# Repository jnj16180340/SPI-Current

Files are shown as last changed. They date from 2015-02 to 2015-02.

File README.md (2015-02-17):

# SPI-Current
Schematic and boards for power supply  

**Versions: **
Beefy and Wimpy: Wimpy has heatsinks+coils removed; traces are smaller; board is shrunk a lot

**TODO:**  
* Wall voltage fuse, stepdown, rectify, filter
* Make a branch with 2 independent half bridges in it
* Isolate the 12V stuff from the 5v stuff
* Figure out filtering caps for hall sensors
* Add fuse to output
* Lay out boards  

**NOTES:** 
* Traces won't take much current-- Only about 5 amps or so. Ideally we can OMIT the traces entirely and wire up with wire. Or, beel up the traces with solder by OMITTING the mask
* Use 10 gauge wire
* Replace shunt resistors x2 with thick wire jumper, unless you omit the hall sensors
* Replace a hall sensor with wire jumper unless you want two redundant ones
* Values for L#, may depend on the load
* Gain of output buffer: If ACS758 is 60mV/A, then max (50A) is 3. Want gain = 5/3
* 12V gets an XT60 connector, rated to 60A
* So does output to peltiers
* DIS jumper disables the drivers...
* If you power up the HIP4081 backwards it DIES.

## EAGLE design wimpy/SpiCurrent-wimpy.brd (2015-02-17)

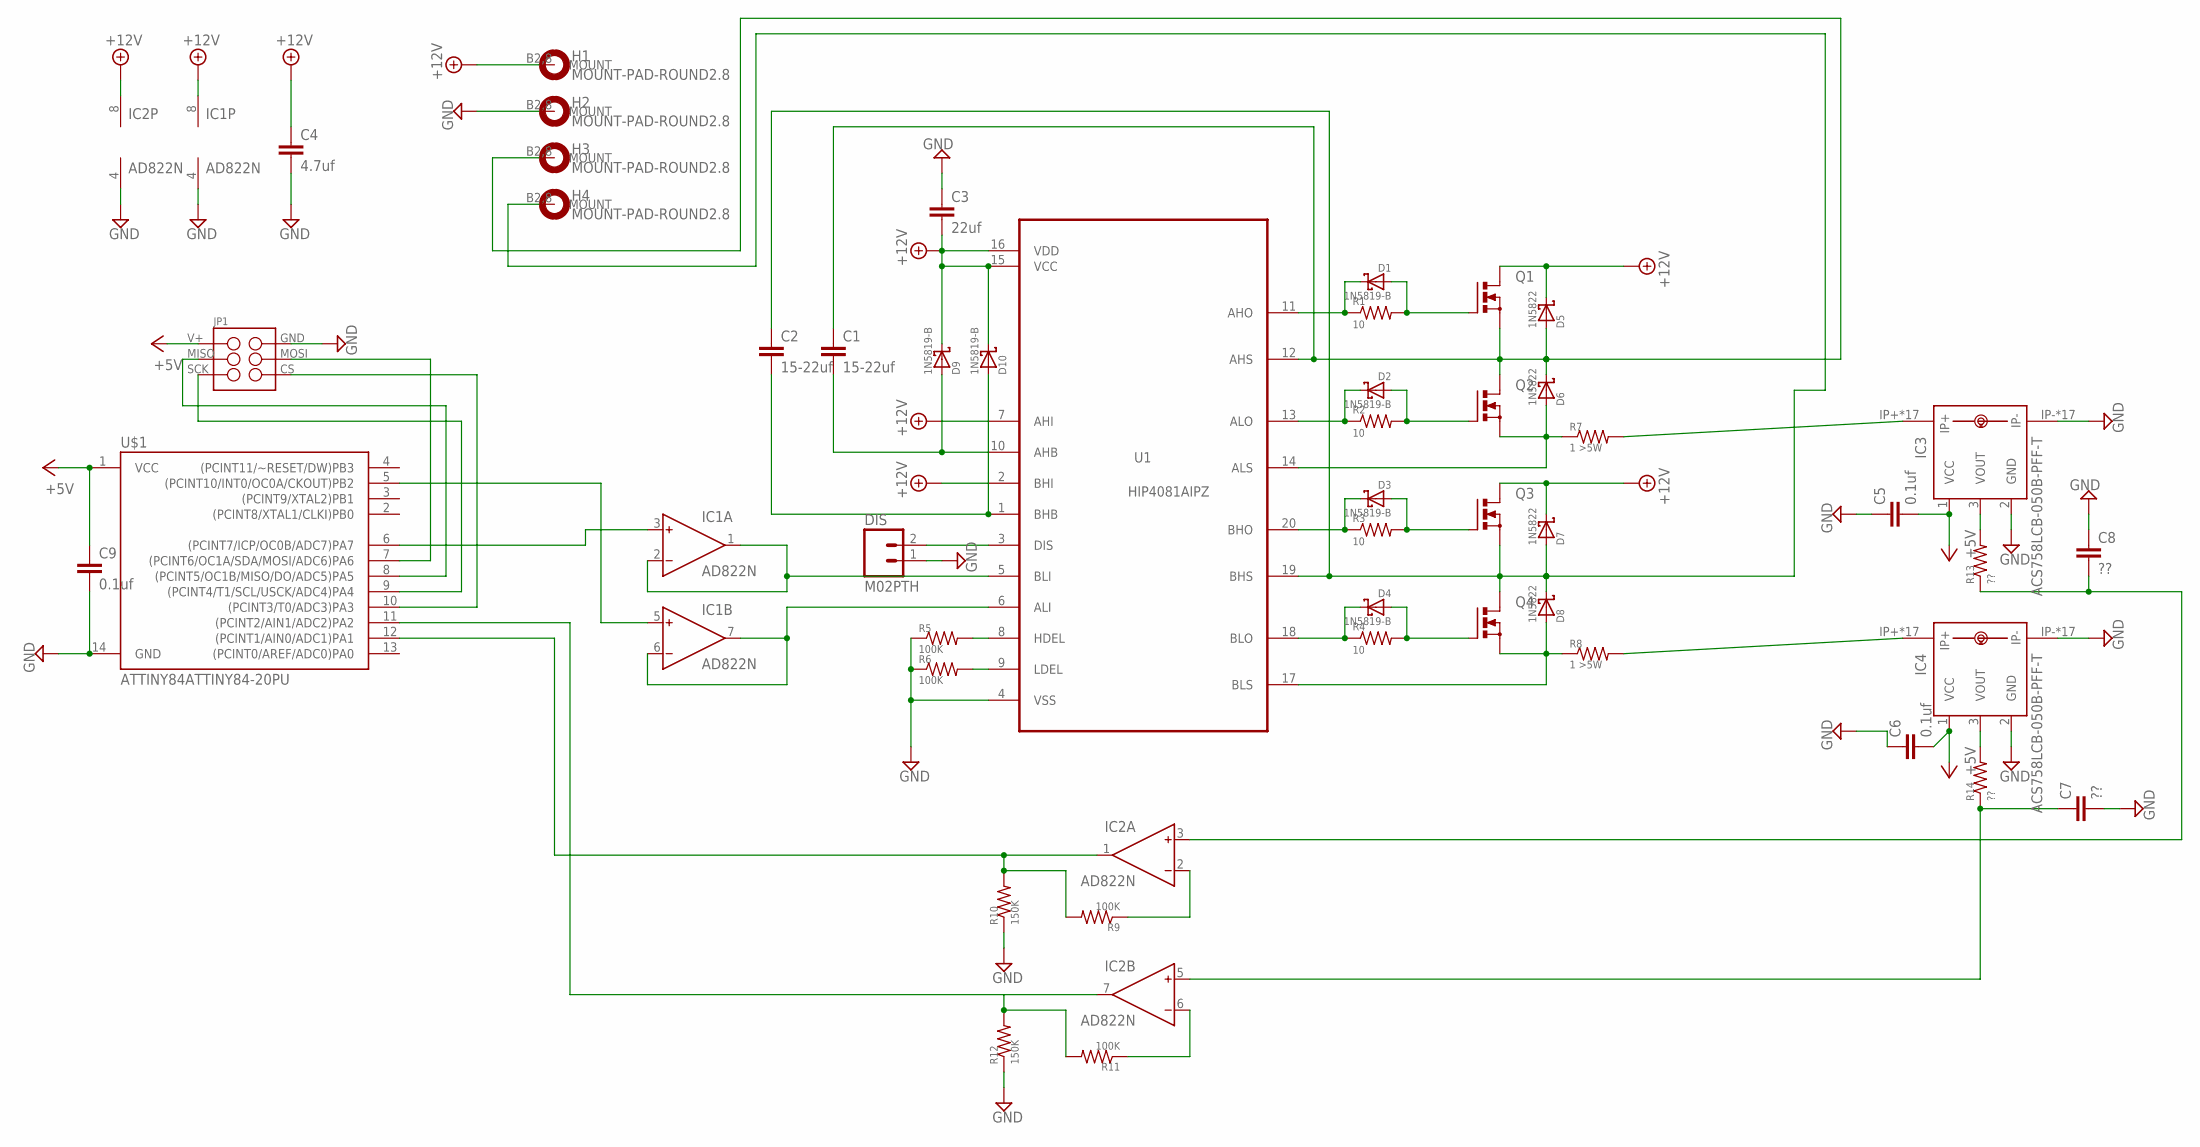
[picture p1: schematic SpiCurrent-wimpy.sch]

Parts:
C1, C2: 15-22uf; C050-055X075
C3: 22uf; C050-055X075
C4: 4.7uf; C050-055X075
C5, C6, C9: 0.1uf; C050-055X075
C7, C8: ??; C050-055X075
D1, D2, D3, D4, D9, D10: 1N5819-B; DO41-7.6
D5, D6, D7, D8: 1N5822; DO41-7.6
DIS: M02PTH; 1X02
H1, H2, H3, H4: MOUNT-PAD-ROUND2.8; 2,8-PAD
IC1, IC2: AD822N; DIL08
IC3, IC4: ACS758LCB-050B-PFF-T; CB-PFF
JP1: M03X2SHROUD; 2X3-SPI-SHROUDED
Q1, Q2, Q3, Q4: PMOSFET_NTO220BV; TO220BV
R1, R2, R3, R4: 10; 0207/10
R5, R6, R9, R11: 100K; 0207/10
R7, R8: 1 >5W; VTA54
R10, R12: 150K; 0207/10
R13, R14: ??; 0207/10
U1: HIP4081AIPZ; DIP254P762X533-20
U$1: ATTINY84ATTINY84-20PU; DIL14

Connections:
+5V: C5.2, C6.2, C9.1, IC3.1 (VCC), IC4.1 (VCC), JP1.1, U$1.1 (VCC)
+12V: C3.2, C4.1, D5.C, D7.C, D9.C, D10.C, H1.B2,8, IC1.8 (V+), IC2.8 (V+), Q1.D, Q3.D, U1.2 (BHI), U1.7 (AHI), U1.15 (VCC), U1.16 (VDD)
,JHBKLJN: C1.1, D5.A, D6.C, H3.B2,8, Q1.S, Q2.D, U1.12 (AHS)
GND: C3.1, C4.2, C5.1, C6.1, C7.2, C8.1, C9.2, DIS.1, H2.B2,8, IC1.4 (V-), IC2.4 (V-), IC3.2 (GND), IC3.IP-, IC3.IP-@2 (IP-), IC3.IP-@3 (IP-), IC3.IP-@4 (IP-), IC3.IP-@5 (IP-), IC3.IP-@6 (IP-), IC3.IP-@7 (IP-), IC3.IP-@8 (IP-), IC3.IP-@9 (IP-), IC3.IP-@10 (IP-), IC3.IP-@11 (IP-), IC3.IP-@12 (IP-), IC3.IP-@13 (IP-), IC3.IP-@14 (IP-), IC3.IP-@15 (IP-), IC3.IP-@16 (IP-), IC3.IP-@17 (IP-), IC4.2 (GND), IC4.IP-, IC4.IP-@2 (IP-), IC4.IP-@3 (IP-), IC4.IP-@4 (IP-), IC4.IP-@5 (IP-), IC4.IP-@6 (IP-), IC4.IP-@7 (IP-), IC4.IP-@8 (IP-), IC4.IP-@9 (IP-), IC4.IP-@10 (IP-), IC4.IP-@11 (IP-), IC4.IP-@12 (IP-), IC4.IP-@13 (IP-), IC4.IP-@14 (IP-), IC4.IP-@15 (IP-), IC4.IP-@16 (IP-), IC4.IP-@17 (IP-), JP1.2, R5.1, R6.1, R10.1, R12.1, U1.4 (VSS), U$1.14 (GND)
unnamed: IC1.1 (OUT), IC1.2 (IN-), U1.5 (BLI)
unnamed: IC1.6 (IN-), IC1.7 (OUT), U1.6 (ALI)
unnamed: D3.C, R3.1, U1.20 (BHO)
unnamed: D3.A, Q3.G, R3.2
unnamed: D4.C, R4.1, U1.18 (BLO)
unnamed: D4.A, Q4.G, R4.2
unnamed: D2.C, R2.1, U1.13 (ALO)
unnamed: D2.A, Q2.G, R2.2
unnamed: D1.C, R1.1, U1.11 (AHO)
unnamed: D1.A, Q1.G, R1.2
unnamed: R5.2, U1.8 (HDEL)
unnamed: R6.2, U1.9 (LDEL)
unnamed: C2.1, D7.A, D8.C, H4.B2,8, Q3.S, Q4.D, U1.19 (BHS)
unnamed: D6.A, Q2.S, R7.1, U1.14 (ALS)
unnamed: D8.A, Q4.S, R8.1, U1.17 (BLS)
unnamed: C1.2, D9.A, U1.10 (AHB)
unnamed: C2.2, D10.A, U1.1 (BHB)
unnamed: DIS.2, U1.3 (DIS)
unnamed: JP1.4, U$1.7 ((PCINT6/OC1A/SDA/MOSI/ADC6)PA6)
unnamed: JP1.3, U$1.8 ((PCINT5/OC1B/MISO/DO/ADC5)PA5)
unnamed: JP1.5, U$1.9 ((PCINT4/T1/SCL/USCK/ADC4)PA4)
unnamed: JP1.6, U$1.10 ((PCINT3/T0/ADC3)PA3)
unnamed: IC1.5 (IN+), U$1.5 ((PCINT10/INT0/OC0A/CKOUT)PB2)
unnamed: IC1.3 (IN+), U$1.6 ((PCINT7/ICP/OC0B/ADC7)PA7)
unnamed: IC2.2 (IN-), R9.1
unnamed: IC4.IP+, IC4.IP+@2 (IP+), IC4.IP+@3 (IP+), IC4.IP+@4 (IP+), IC4.IP+@5 (IP+), IC4.IP+@6 (IP+), IC4.IP+@7 (IP+), IC4.IP+@8 (IP+), IC4.IP+@9 (IP+), IC4.IP+@10 (IP+), IC4.IP+@11 (IP+), IC4.IP+@12 (IP+), IC4.IP+@13 (IP+), IC4.IP+@14 (IP+), IC4.IP+@15 (IP+), IC4.IP+@16 (IP+), IC4.IP+@17 (IP+), R8.2
unnamed: IC2.1 (OUT), R9.2, R10.2, U$1.12 ((PCINT1/AIN0/ADC1)PA1)
unnamed: IC2.7 (OUT), R11.2, R12.2, U$1.11 ((PCINT2/AIN1/ADC2)PA2)
unnamed: IC2.6 (IN-), R11.1
unnamed: IC3.IP+, IC3.IP+@2 (IP+), IC3.IP+@3 (IP+), IC3.IP+@4 (IP+), IC3.IP+@5 (IP+), IC3.IP+@6 (IP+), IC3.IP+@7 (IP+), IC3.IP+@8 (IP+), IC3.IP+@9 (IP+), IC3.IP+@10 (IP+), IC3.IP+@11 (IP+), IC3.IP+@12 (IP+), IC3.IP+@13 (IP+), IC3.IP+@14 (IP+), IC3.IP+@15 (IP+), IC3.IP+@16 (IP+), IC3.IP+@17 (IP+), R7.2
unnamed: C8.2, IC2.3 (IN+), R13.1
unnamed: C7.1, IC2.5 (IN+), R14.1
unnamed: IC3.3 (VOUT), R13.2
unnamed: IC4.3 (VOUT), R14.2

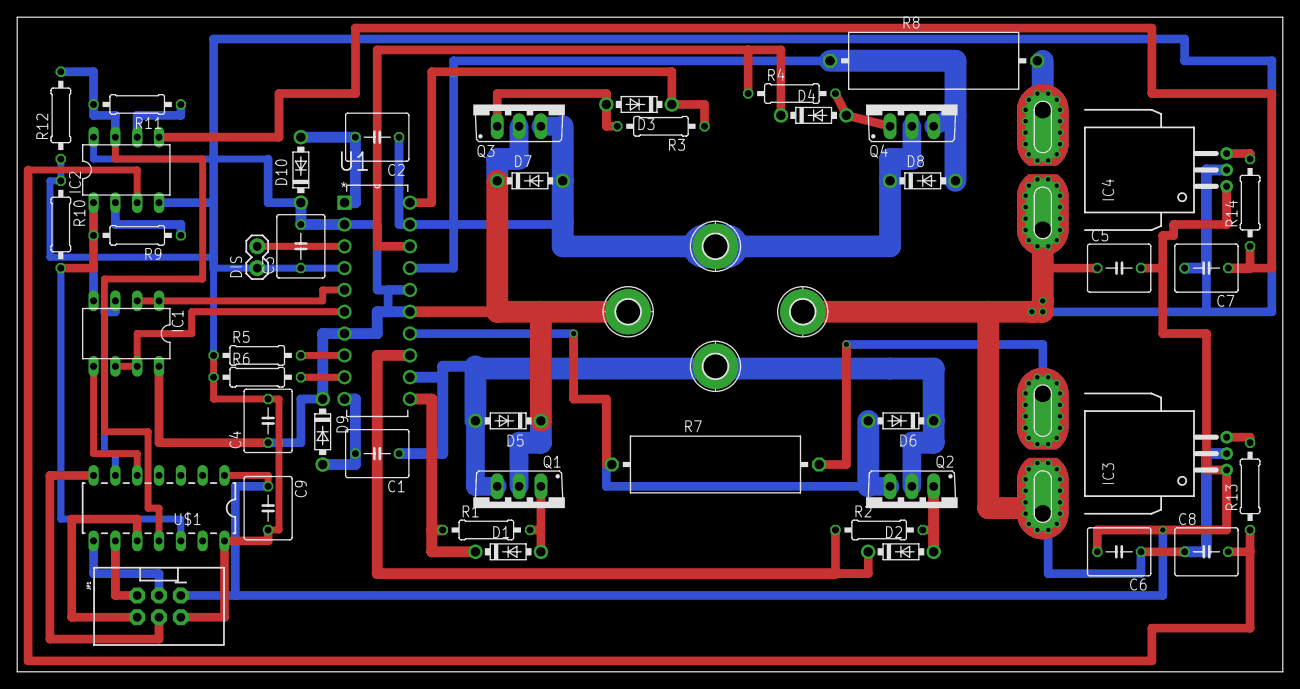
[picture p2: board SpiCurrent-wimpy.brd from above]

Board: 2 copper layers, 147.3 x 76.2 mm, 49 parts (0 on the bottom side), 38 nets.

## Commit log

2015-02-13 Added MCU and hall effect sensor
    [SpiCurrent-New.sch]
2015-02-14 barely begun layout
    [SpiCurrent-New.brd, SpiCurrent-Old-WithShunt.sch]
2015-02-15 begun layout
    [SpiCurrent-New.sch]
2015-02-15 Grossly laid out; still need to check (C5 is weird), check traces, adjust trace widths etc
    [SpiCurrent-New.brd]
2015-02-16 Layout complete. NB fancy mask stuff is NOT complete, use this one for low(ish) current testing
    [SpiCurrent-New.brd]
2015-02-17 Made beefy abnd wimpy versions
    [SpiCurrent-beefy.brd, SpiCurrent-beefy.sch, SpiCurrent-wimpy.brd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]
2015-02-17 removed old crap
    [SpiCurrent-New.brd, SpiCurrent-New.sch, SpiCurrent-Old-WithShunt.sch]

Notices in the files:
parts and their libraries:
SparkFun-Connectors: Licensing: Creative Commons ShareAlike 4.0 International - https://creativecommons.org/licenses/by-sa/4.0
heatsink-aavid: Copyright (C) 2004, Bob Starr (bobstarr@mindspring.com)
